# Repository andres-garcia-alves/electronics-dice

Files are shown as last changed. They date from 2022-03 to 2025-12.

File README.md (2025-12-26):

# Electronic-Dice

Arduino &amp; PIC16F84A source code & building details for an electronic dice (with animations). 

Available animations:
- #01: corner leds followed by the central one
- #02: perimeter leds followed by the central one
- #03: loop row-by-row from upper to bottom
- #04: bounce row-by-row from upper to bottom
- #05: go one-by-one over leds perimeter
- #06: a dot going in horizontal lines
- #07: a dot going in vertical lines
- #08: a dot going in zig-zag
- #09: loop of horizontal and vertical lines
- #10: a dot going in vertical lines followed by horizontal ones
- #11: random dots
- #12: random dots fill
- #13: random dot fill & random dot empty

&nbsp;

This project use the following electronic components:
-  1 x Arduino UNO / Nano v3
-  1 x push-button
-  1 x switch-button
-  7 x red LEDs
-  7 x 330 ohm resistors
-  1 x ON/OFF button
-  1 x blue LED
-  1 x 10k ohm resistor
-  1 x experimental board (single face) 6x8cm
-  1 x experimental board (double face) 6x8cm
-  1 x 9v battery
-  1 x small plastic box
- 10 x short female wires
- 20 x male 90 degrees pins

The circuit:
- Dice button attached to pin 2
- Switch button attached to pin 3 (enable/disable animations)
- Red LEDs attached to pins 4-10 (see code comments for details)

Pinout:

      *(A)        *(B)

      *(C)  *(D)  *(E)

      *(F)        *(G)

  - D02 -> input with button interrupt
  - D03 -> input with switch
  - D04 -> output to bottom-right led (G)
  - D05 -> output to middle-right led (E)
  - D06 -> output to upper-right led (B)
  - D07 -> output to middle-center led (D)
  - D08 -> output to bottom-left led (F)
  - D09 -> output to middle-left led (C)
  - D10 -> output to upper-left led (A)

&nbsp;

### Screenshots

| Schematics | PCB Layout |
|---|---|
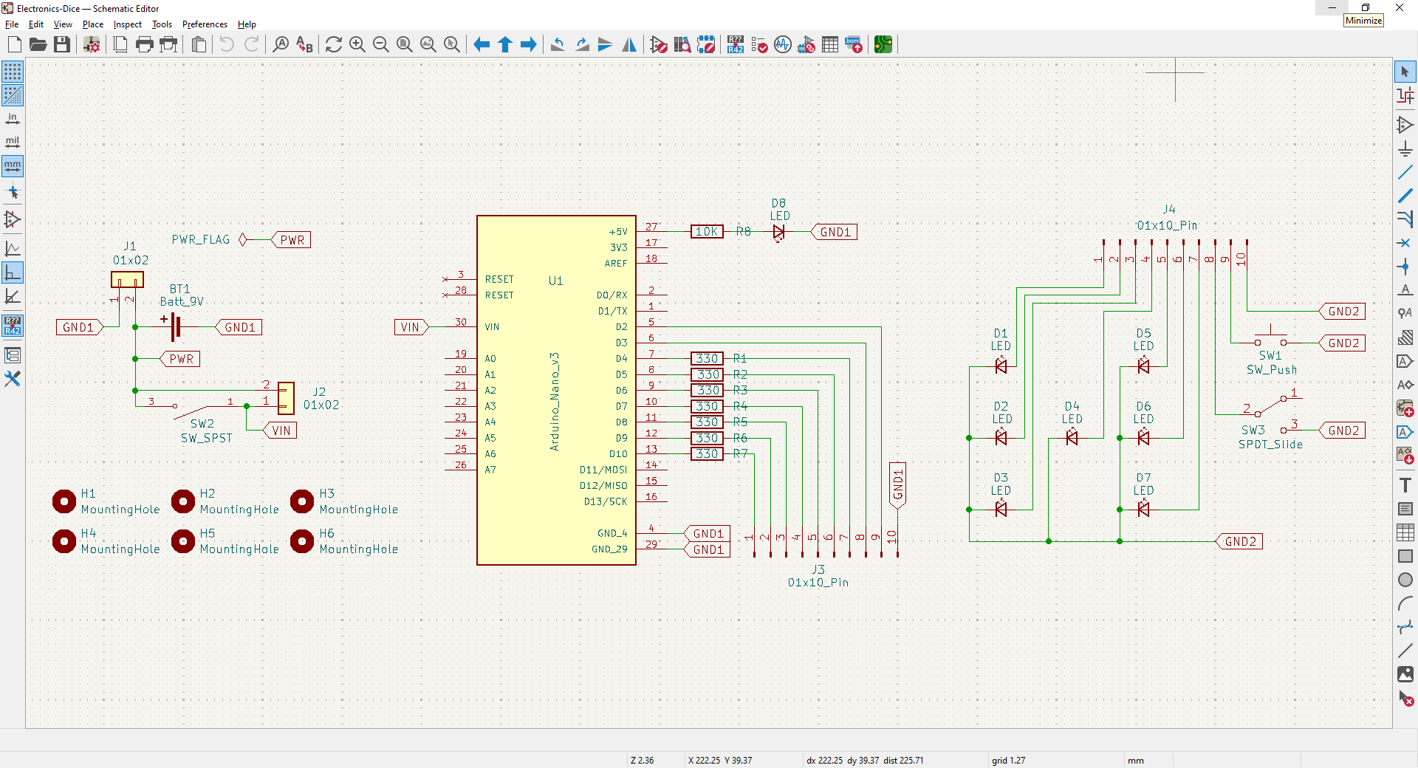
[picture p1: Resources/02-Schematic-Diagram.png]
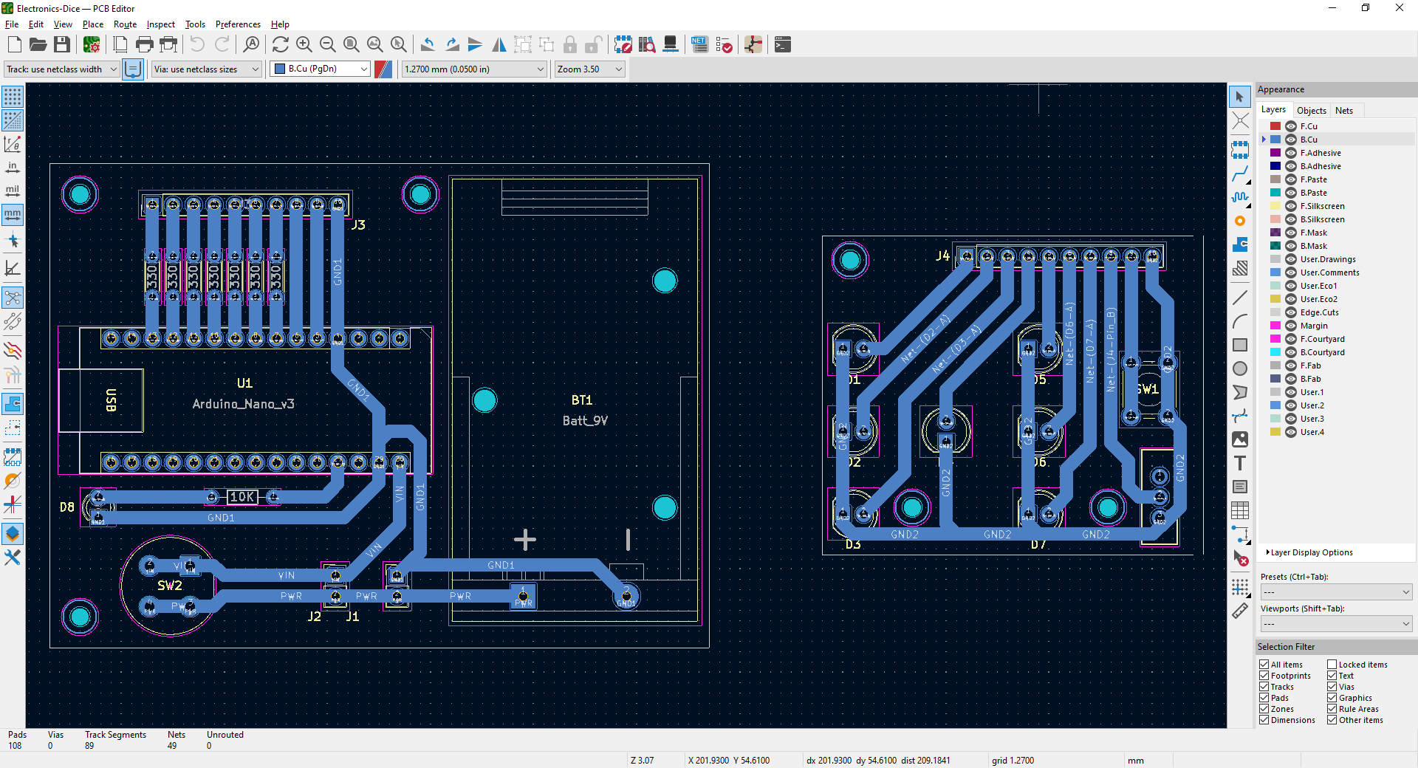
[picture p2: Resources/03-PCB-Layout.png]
|   |  |

| PCB 3D Render | PCB 3D Render |
|---|---|
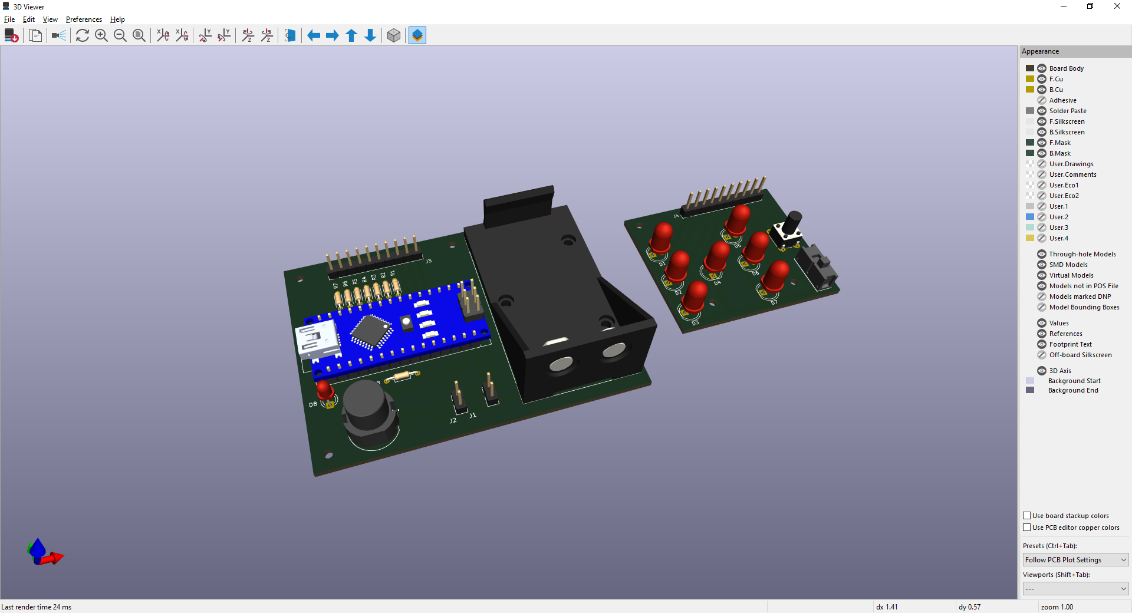
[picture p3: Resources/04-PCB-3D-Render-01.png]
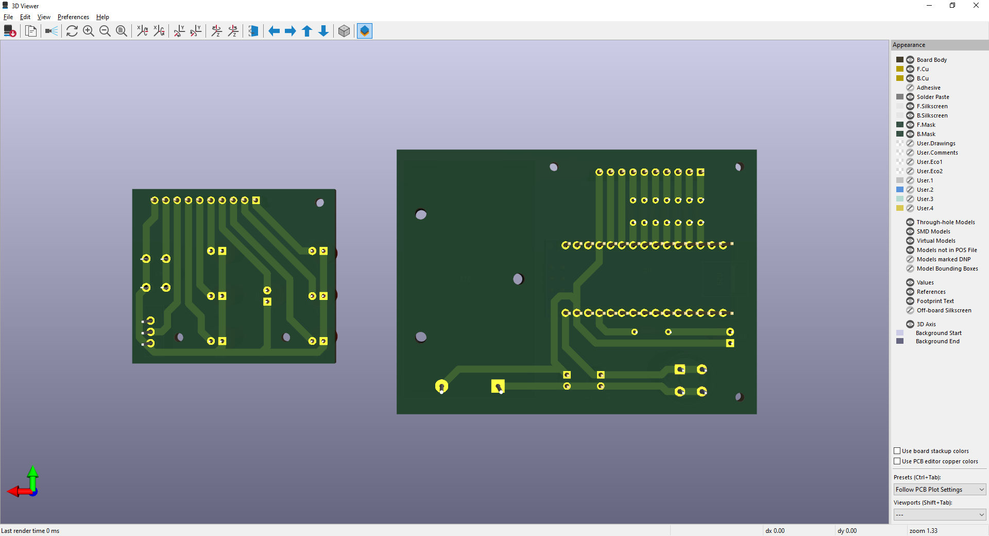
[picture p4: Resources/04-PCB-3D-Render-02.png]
|  |  |

| Prototype |  Prototype |
|---|---|
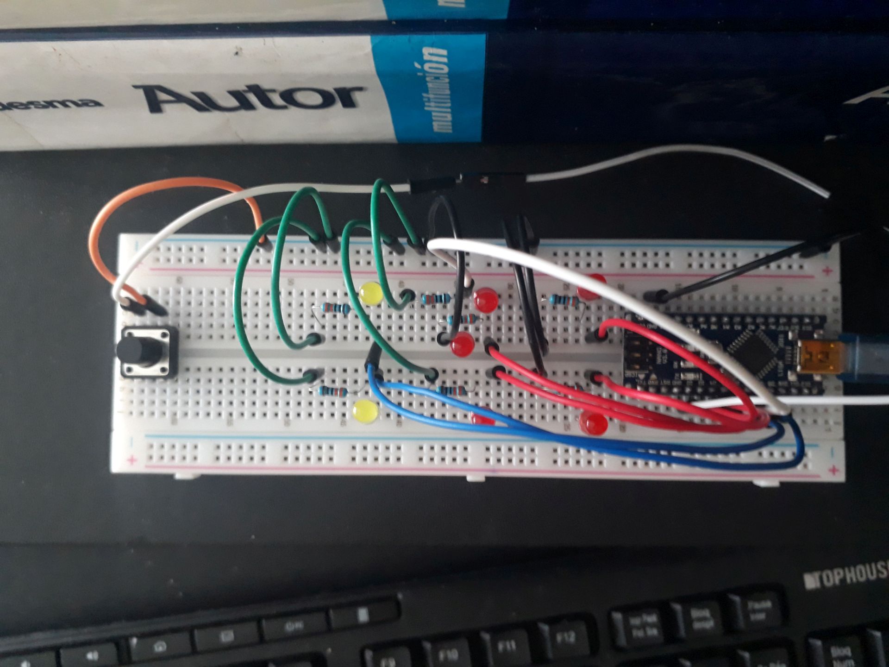
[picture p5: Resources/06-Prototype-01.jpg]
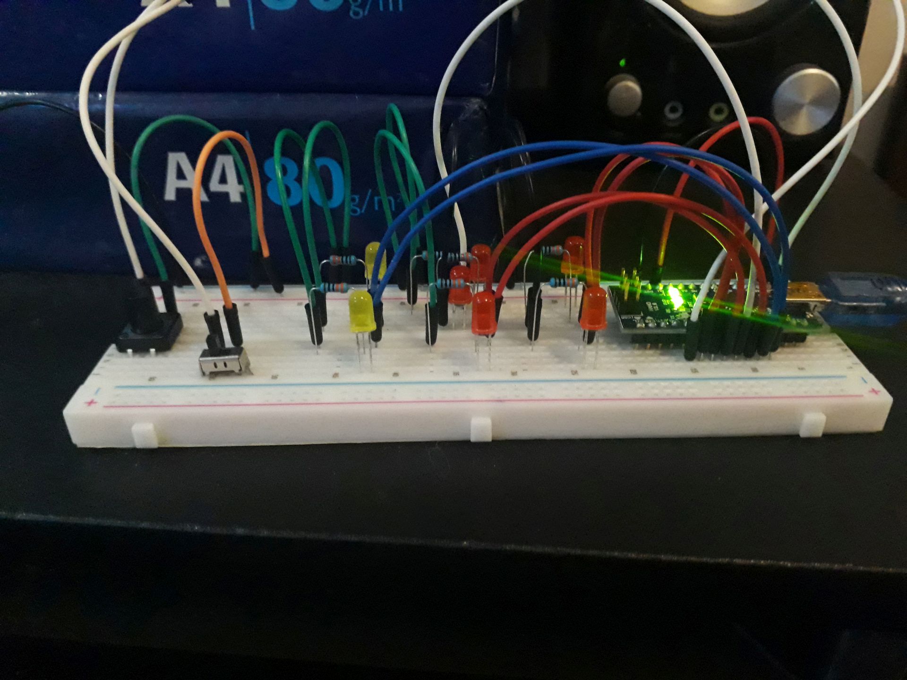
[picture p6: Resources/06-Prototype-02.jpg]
|  |  |

| Building |  Building |
|---|---|
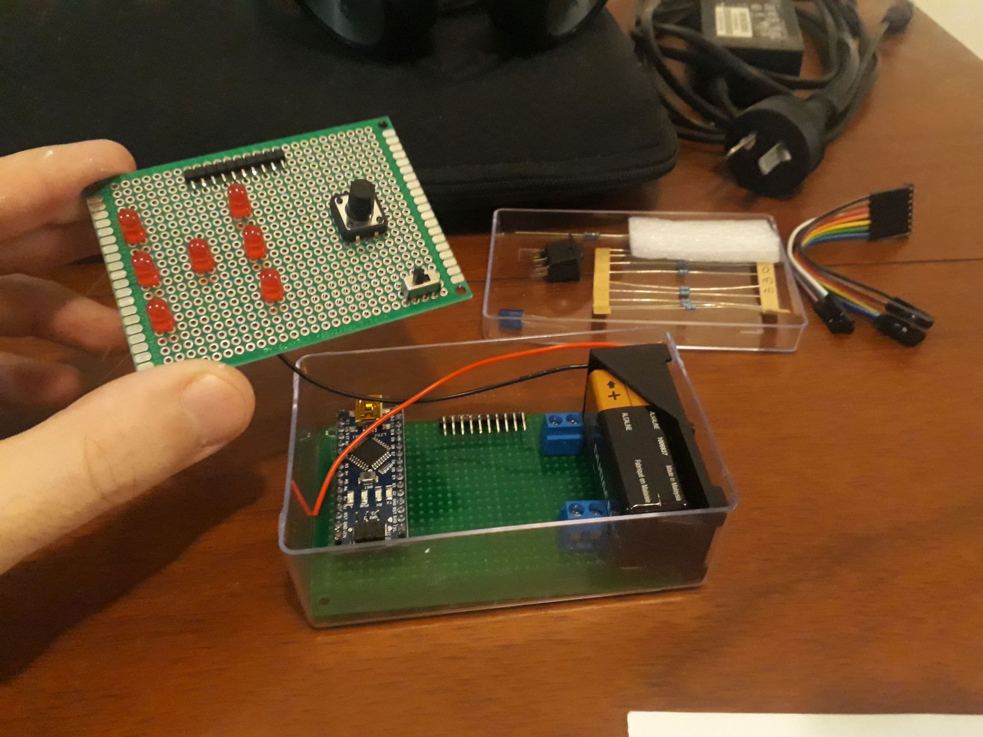
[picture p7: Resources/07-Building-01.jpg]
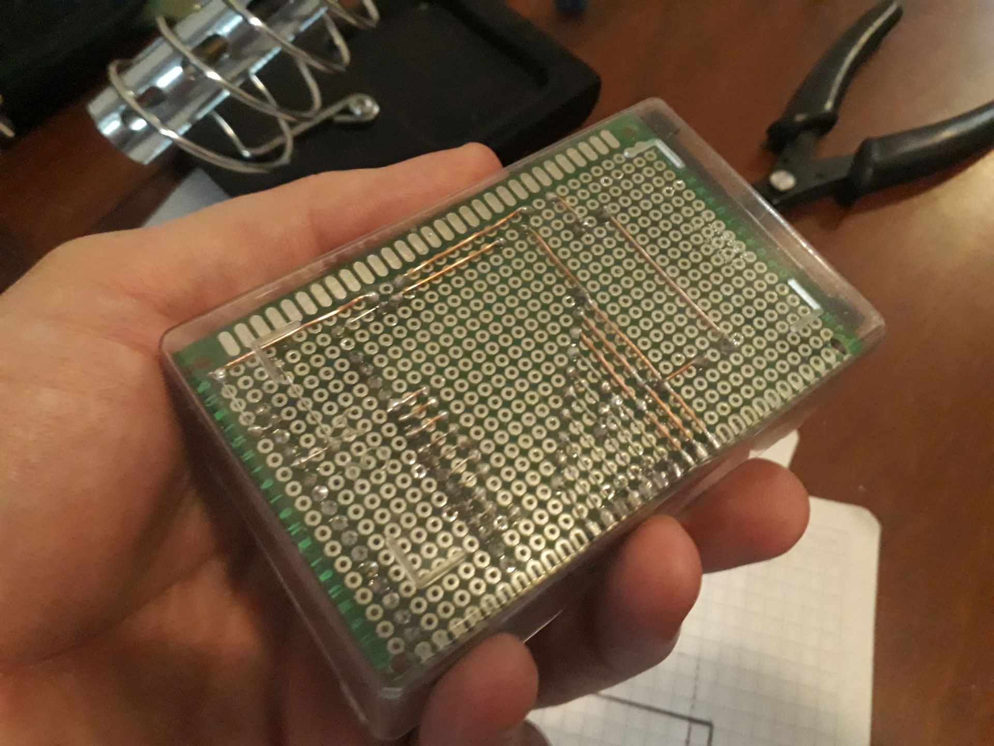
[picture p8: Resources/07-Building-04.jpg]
|  |  |

| Building |  Building |
|---|---|
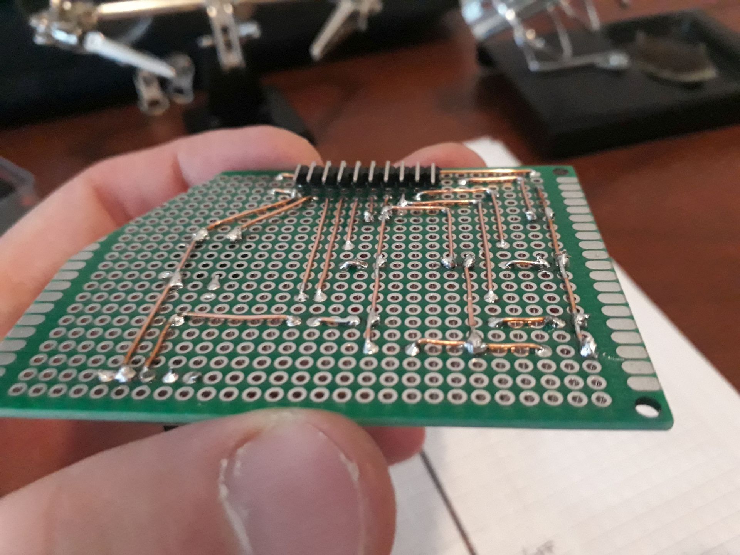
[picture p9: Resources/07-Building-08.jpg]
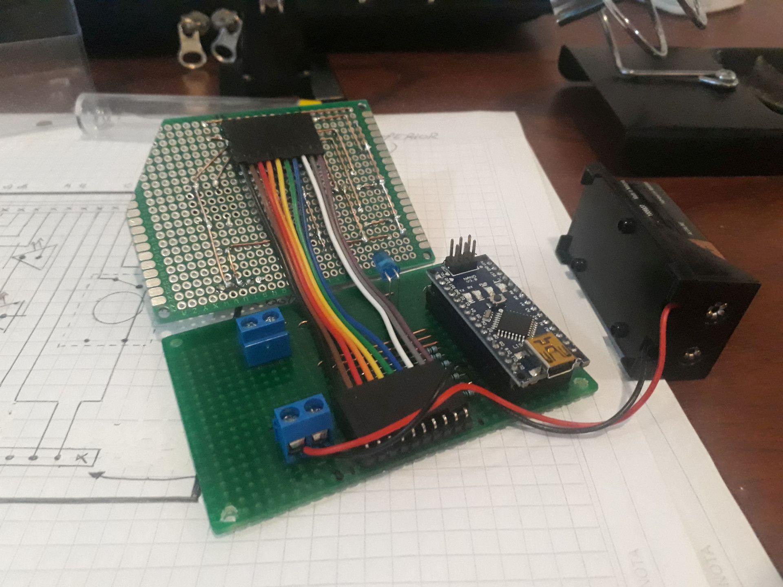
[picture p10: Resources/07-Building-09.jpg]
|  |  |

| Project Final | Project Final (YouTube video) |
|---|---|
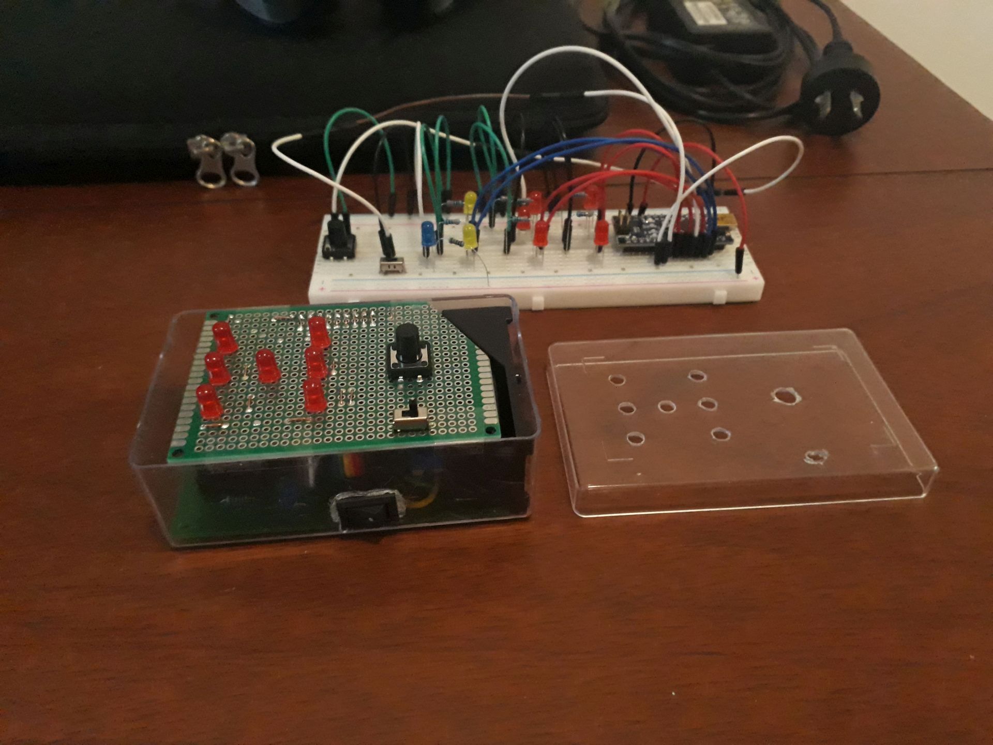
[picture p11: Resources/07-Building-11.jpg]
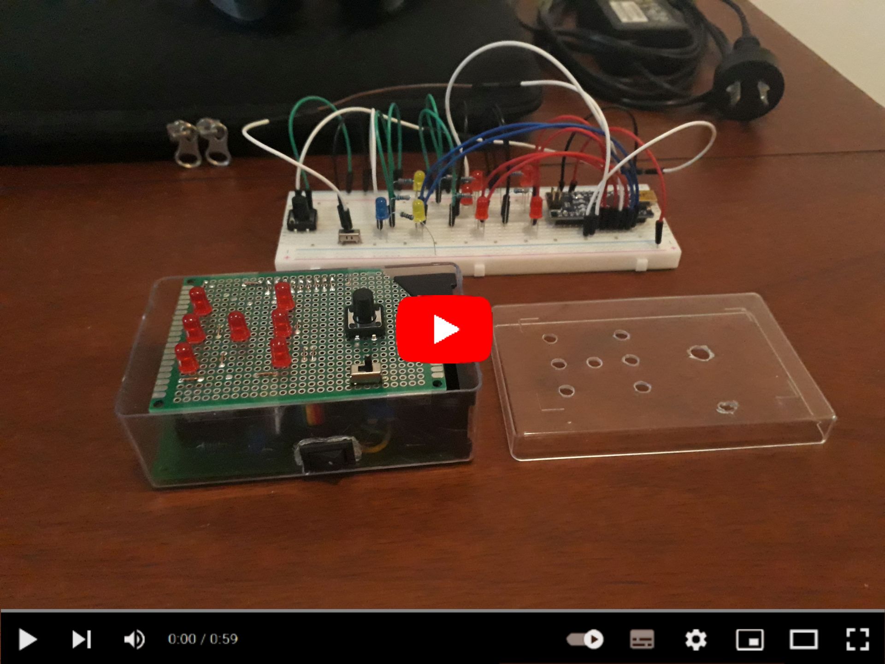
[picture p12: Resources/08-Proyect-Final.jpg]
(https://youtu.be/CFKjGjXlMMI)
|  |  |

See 'Rescources' sub-folder for more pictures & videos of the project.

&nbsp;

### Version History

v1.0 (2022.02.23) - Initial release.  
v1.1 (2022.02.24) - Adding ON/OFF animations switch. Fixed bug with random secuences (randomSeed).  
v1.2 (2022.02.27) - Re-arrange LEDs pin-out to simplify PCB.  
v1.3 (2022.03.09) - Animations improved with ROM tables: line count 622->342 (compiled size reduced by 20%).  
v1.4 (2022.03.10) - Dice number improved with masked bits: line count 342 -> 296.  
v1.5 (2025.12.26) - Adding KiCAD 9 schematics and PCB diagrams.

&nbsp;

This source code is licensed under GPL v3.0  
Please send me your feedback about this project: andres.garcia.alves@gmail.com

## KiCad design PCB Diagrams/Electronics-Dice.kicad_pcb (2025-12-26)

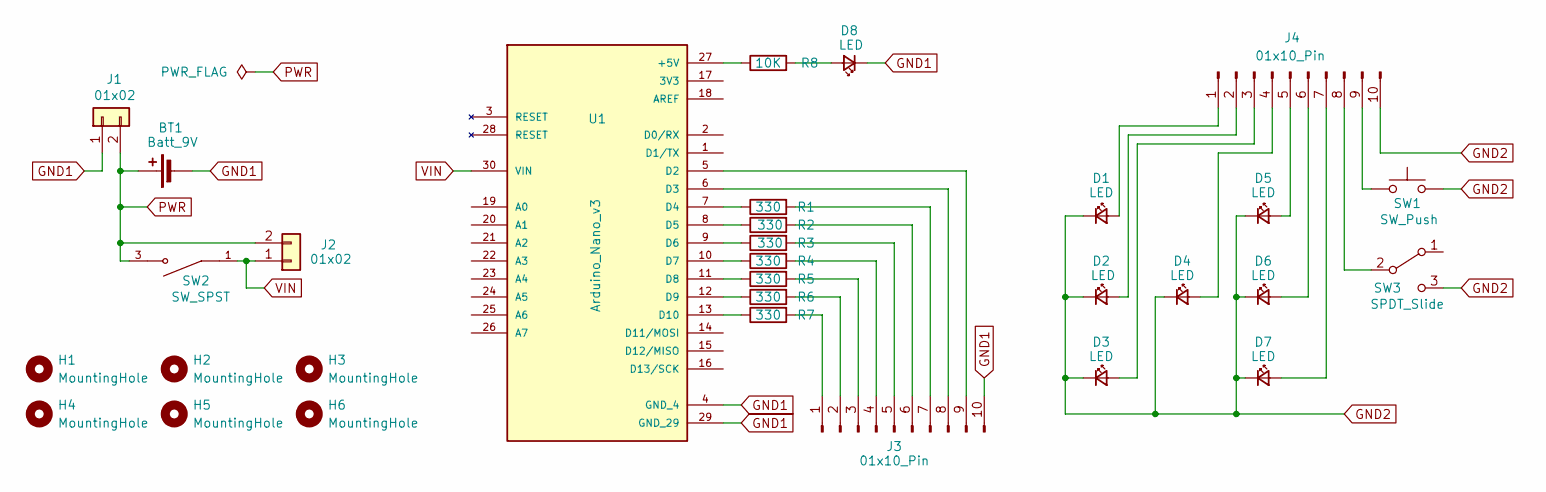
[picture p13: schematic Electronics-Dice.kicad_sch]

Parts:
BT1: Batt_9V; BatteryHolder_Eagle_12BH611-GR
D1, D2, D3, D4, D5, D6, D7: LED; LED_D5.0mm
D8: LED; LED_D3.0mm
H1, H2, H3, H4, H5, H6: MountingHole; MountingHole_2mm
J1, J2: 01x02; PinHeader_1x02_P2.54mm_Vertical
J3, J4: 01x10_Pin; PinHeader_1x10_P2.54mm_Vertical
R1, R2, R3, R4, R5, R6, R7: 330; R_Axial_DIN0204_L3.6mm_D1.6mm_P5.08mm_Horizontal
R8: 10K; R_Axial_DIN0204_L3.6mm_D1.6mm_P7.62mm_Horizontal
SW1: SW_Push; SW_PUSH_6mm_H9.5mm
SW2: SW_SPST; Push_Button_Switch_THT_C&K_D6R90LGS
SW3: SPDT_Slide; Slide_SPDT_PTH_11.6x4.0mm
U1: Arduino_Nano_v3

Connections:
GND1: BT1.2 (-), D8.1 (K), J1.1, J3.10, U1.4 (GND_4), U1.29 (GND_29)
GND2: D1.1 (K), D2.1 (K), D3.1 (K), D4.1 (K), D5.1 (K), D6.1 (K), D7.1 (K), J4.10, SW1.2, SW3.3 (C)
unnamed: D1.2 (A), J4.1
unnamed: D2.2 (A), J4.2
unnamed: D3.2 (A), J4.3
unnamed: D4.2 (A), J4.4
unnamed: D5.2 (A), J4.5
unnamed: D6.2 (A), J4.6
unnamed: D7.2 (A), J4.7
unnamed: D8.2 (A), R8.2
unnamed: J3.1, R7.2
unnamed: J3.2, R6.2
unnamed: J3.3, R5.2
unnamed: J3.4, R4.2
unnamed: J3.5, R3.2
unnamed: J3.6, R2.2
unnamed: J3.7, R1.2
unnamed: J3.8, U1.6 (D3)
unnamed: J3.9, U1.5 (D2)
unnamed: J4.8, SW3.2 (B)
unnamed: J4.9, SW1.1
unnamed: R8.1, U1.27 (+5V)
unnamed: R1.1, U1.7 (D4)
unnamed: R2.1, U1.8 (D5)
unnamed: R3.1, U1.9 (D6)
unnamed: R4.1, U1.10 (D7)
unnamed: R5.1, U1.11 (D8)
unnamed: R6.1, U1.12 (D9)
unnamed: R7.1, U1.13 (D10)
PWR: BT1.1 (+), J1.2, J2.2, SW2.3, SW2.4
VIN: J2.1, SW2.1, SW2.2, U1.30 (VIN)

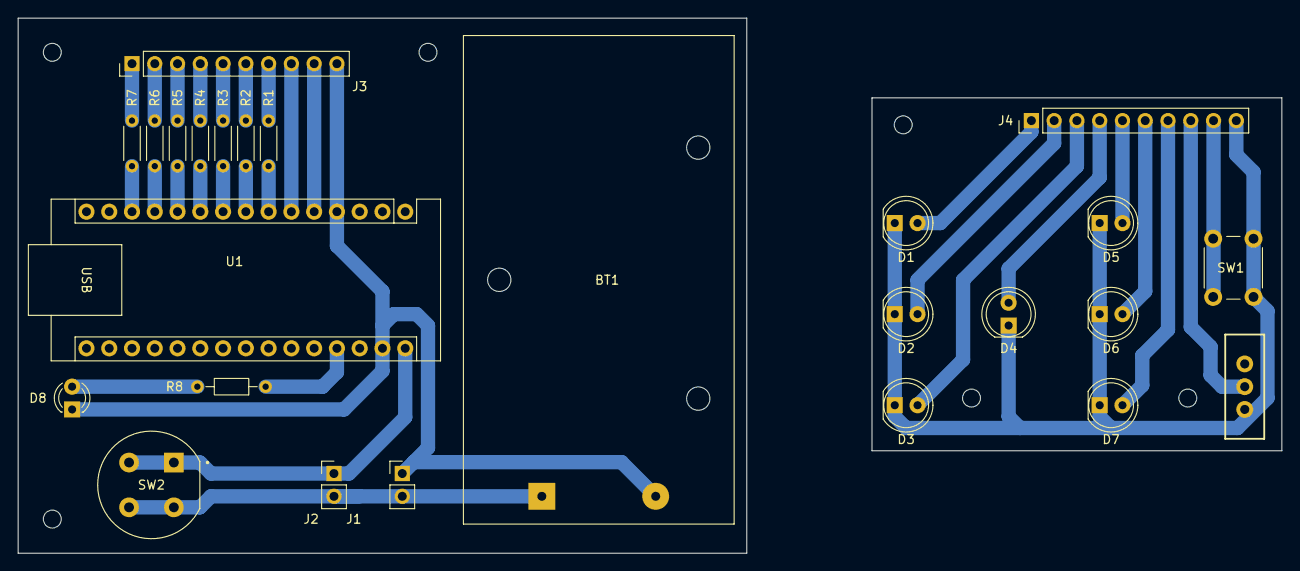
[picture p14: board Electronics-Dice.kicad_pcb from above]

Board: 2 copper layers, 141.0 x 59.7 mm, 31 parts (0 on the bottom side), 31 nets.

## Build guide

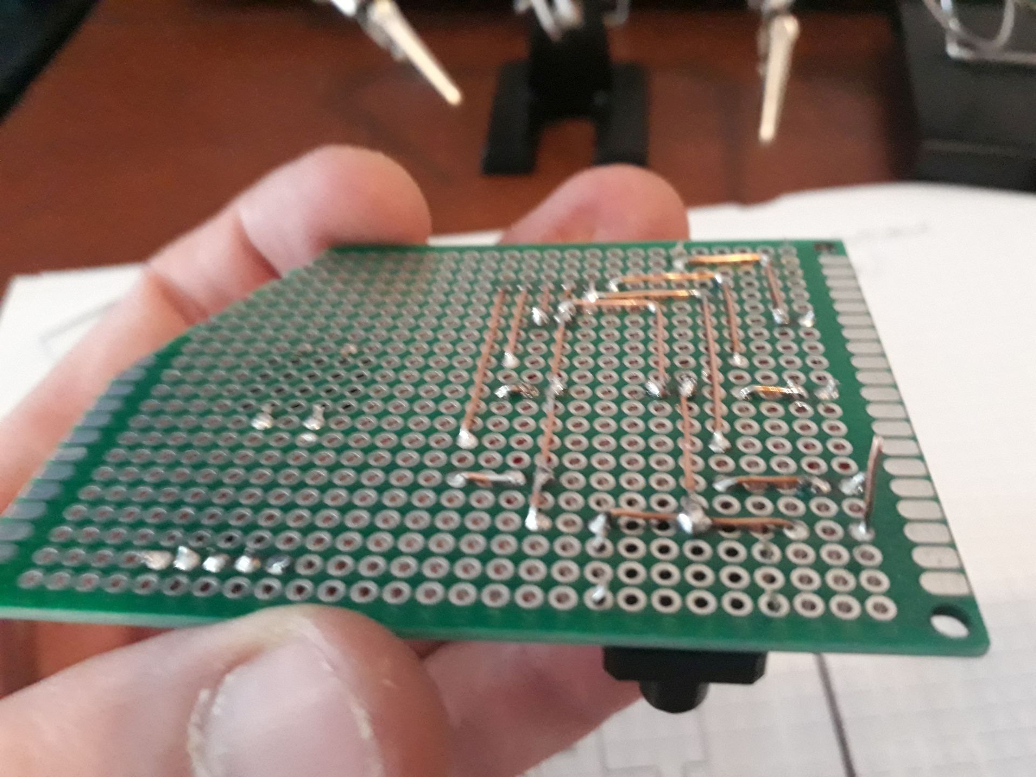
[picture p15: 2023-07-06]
Resources/07-Building-07.jpg

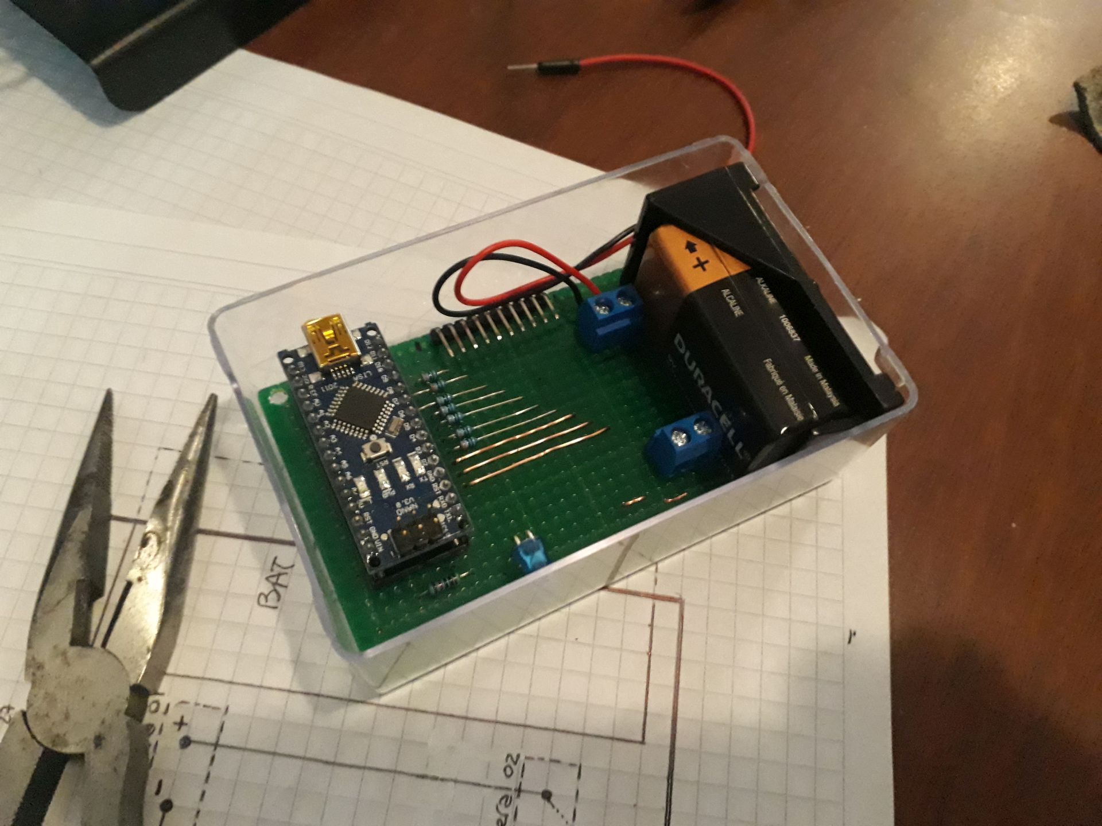
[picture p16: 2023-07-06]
Resources/07-Building-03.jpg

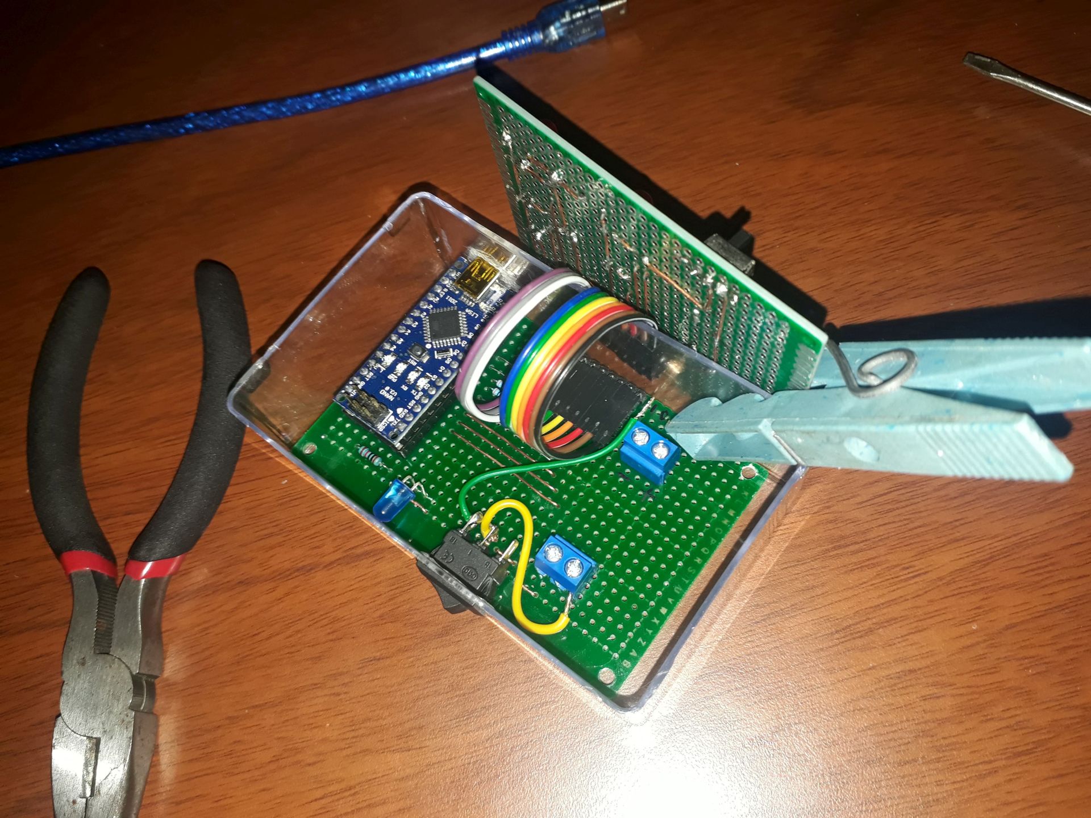
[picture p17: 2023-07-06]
Resources/07-Building-10.jpg

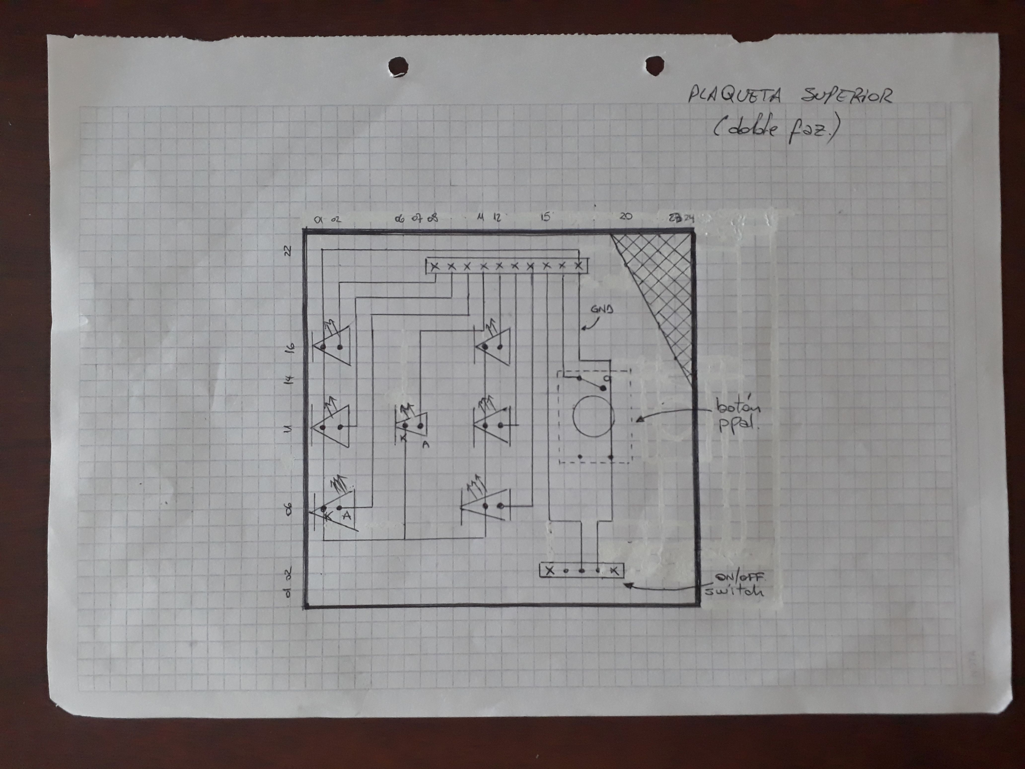
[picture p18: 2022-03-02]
Resources/01-Wiring-Diagram-01.jpg

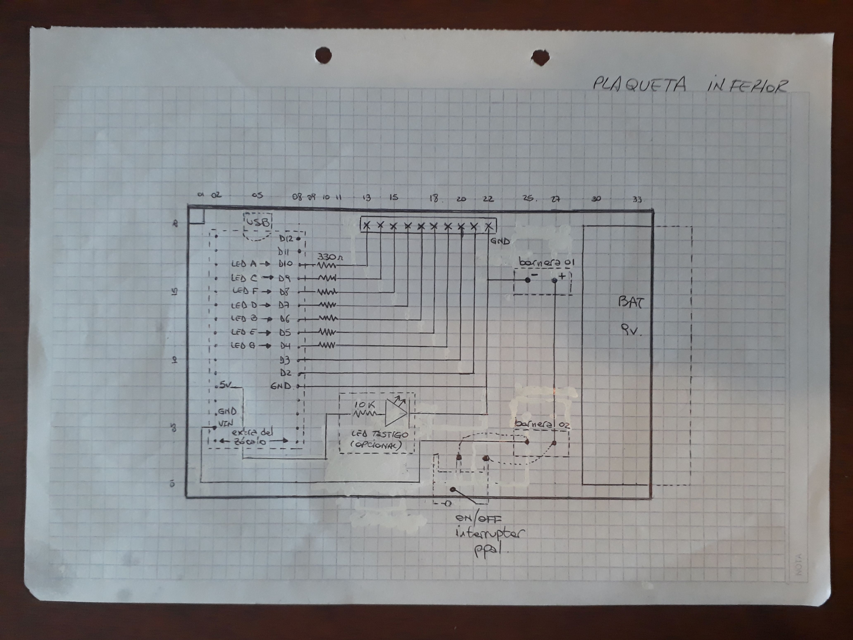
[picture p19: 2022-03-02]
Resources/01-Wiring-Diagram-02.jpg

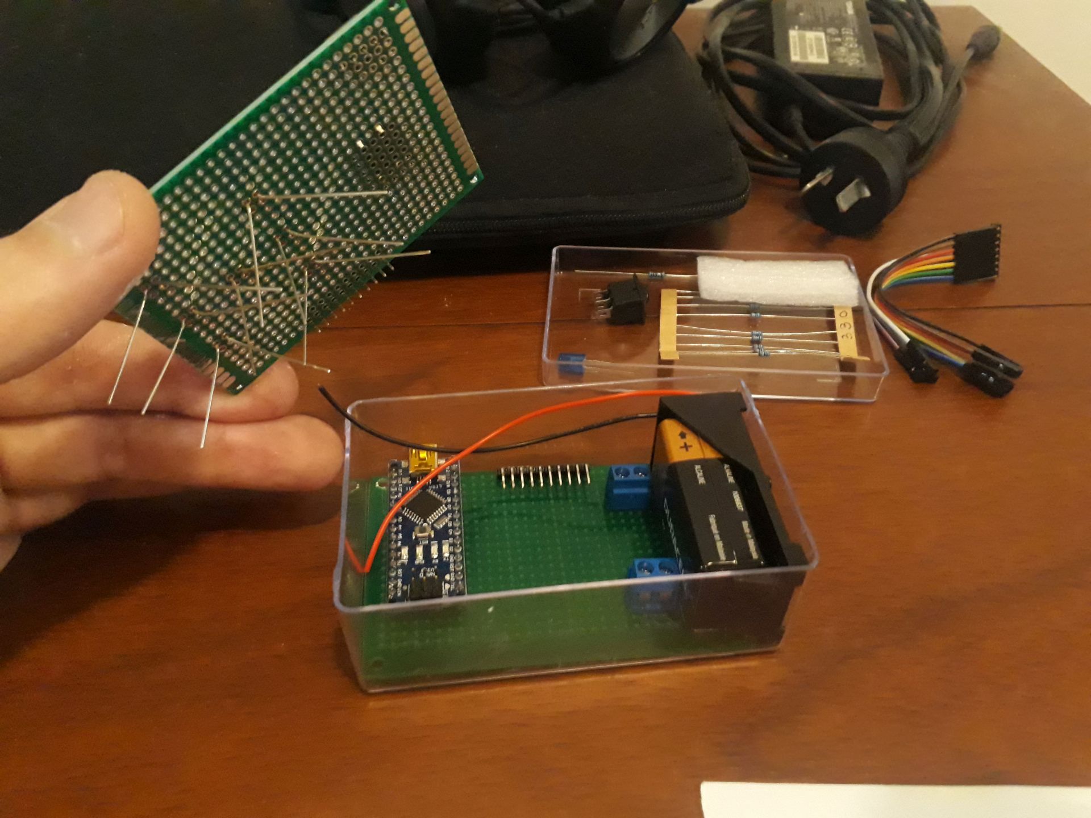
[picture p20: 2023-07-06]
Resources/07-Building-02.jpg

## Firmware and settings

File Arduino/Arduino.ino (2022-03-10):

/*
  Electronic Dice v1.3

  Created by: Andres Garcia Alves <andres.garcia.alves@gmail.com>
  Microcontroller: Arduino Nano (ATMega328 @16Mhz)
  
  Version 1.0, 2022.02.23 - Initial release.
  Version 1.1, 2022.02.24 - Adding ON/OFF animations switch.
                            Fixed bug with random secuences (randomSeed).
  Version 1.2, 2022.02.27 - Re-arrange LEDs pin-out to simplify PCB.
  Version 1.3, 2022.03.09 - Animations improvement using ROM tables: lines count 622->342, compiled total size 6031->4867 bytes (20% reduction).
  Version 1.4, 2022.03.10 - Dice number improvement using masked bits: lines count 342->296, compiled total size 4867->4777 bytes (2% reduction).

  This source code is licensed under GPL v3.0  

  Pinout:
  
      *(A)        *(B)

      *(C)  *(D)  *(E)

      *(F)        *(G)

  D02 -> input with button interrupt
  D03 -> input with switch
  D04 -> output to bottom-right led (G)
  D05 -> output to middle-right led (E)
  D06 -> output to upper-right led (B)
  D07 -> output to middle-center led (D)
  D08 -> output to bottom-left led (F)
  D09 -> output to middle-left led (C)
  D10 -> output to upper-left led (A)
*/

#include <LowPower.h>

// const & variables
const int PIN_BTN = 2;
const int PIN_SWITCH = 3;

const int PIN_LED_A = 10;
const int PIN_LED_B = 6;
const int PIN_LED_C = 9;
const int PIN_LED_D = 7;
const int PIN_LED_E = 5;
const int PIN_LED_F = 8;
const int PIN_LED_G = 4;

const int DEBOUNCE_DELAY = 50;
const int DICE_DELAY = 5000;

const int ANIM_COUNT = 13;
const int ANIM_SPEED_IDX = 0;
const int ANIM_LOOPS_IDX = 1;
const int ANIM_LENGHT_IDX = 2;

const int ANIM_DELAY = 200;
const int ANIM_HALF_DELAY = 100;
const int ANIM_DOUBLE_DELAY = 400;
const int ANIM_ENDING_DELAY = 1000;

// interrupt handlers
void btnInterruptHandler() { }
 

// initial setup
void setup() {

  // CLKPR = 0x80; // (1000 0000) enable change in clock frequency
  // CLKPR = 0x01; // (0000 0001) use clock division factor 2 to reduce the frequency from 16 MHz to 8 MHz

  Serial.begin(9600);

  pinMode(PIN_BTN, INPUT_PULLUP);
  pinMode(PIN_SWITCH, INPUT_PULLUP);
  pinMode(PIN_LED_A, OUTPUT);
  pinMode(PIN_LED_B, OUTPUT);
  pinMode(PIN_LED_C, OUTPUT);
  pinMode(PIN_LED_D, OUTPUT);
  pinMode(PIN_LED_E, OUTPUT);
  pinMode(PIN_LED_F, OUTPUT);
  pinMode(PIN_LED_G, OUTPUT);

  // get some noise value from A0
  randomSeed(analogRead(A0));

  // enable external interrupts on pins 2 & 3
  attachInterrupt(digitalPinToInterrupt(PIN_BTN), btnInterruptHandler, FALLING);
}


// main loop
void loop() {

  // enter in power-down state
  LowPower.powerDown(SLEEP_FOREVER, ADC_OFF, BOD_ON);

  // main button logic
  checkButtonPressed();
}


void checkButtonPressed() {

  // de-bounce delay
  delay(DEBOUNCE_DELAY);
  bool btnStatus = digitalRead(PIN_BTN);
  if (btnStatus != LOW) { return; }

  // throw the dice
  byte diceNumber = (byte)random(1, 7); // range 1-6
  byte animNumber = (byte)random(1, ANIM_COUNT+1); // range 1-ANIM_COUNT

  // animation
  bool switchAnim = digitalRead(PIN_SWITCH);
  if (switchAnim == true) {
    displayAnimation(animNumber);
    delay(ANIM_ENDING_DELAY);
  }

  // display dice number & fade-out
  displayDiceNumber(diceNumber);
  delay(DICE_DELAY);
  animateDiceNumber(diceNumber);
}


void displayDiceNumber(byte diceNumber) {

  clearDice();

  // dice numbers: 0 (invalid), 1, 2, 3, 4, 5, 6
  byte numbersData[7] = { 0b00000000, 0b00001000, 0b01000001, 0b01001001, 0b01100011, 0b01101011, 0b01110111 };

  // set individuals leds ON/OFF by mask (format: 0XXXXXXX)
  displayLedsByMaskedBits(numbersData[diceNumber], HIGH);
}

void animateDiceNumber(byte diceNumber) {
  
  for (int i = 0; i < 6; i++) {
    displayDiceNumber(diceNumber);
    delay(ANIM_DOUBLE_DELAY);
    clearDice();
    delay(ANIM_DELAY);
  }
}


// display an animation by number
void displayAnimation(byte animNumber) {
  
  switch (animNumber) {
    case 1 ... 10: displayStaticAnimation(animNumber); break;
    case 11: displayDynamicAnimation1(); break;
    case 12: displayDynamicAnimation2(); break;
    case 13: displayDynamicAnimation3(); break;
  }
}

// anims #01-10: static animations
void displayStaticAnimation(byte animNumber) {

  // row format: [speed], [loops], [length], [bitmask step #1], [bitmask step #2], [bitmask step #n], [0]
  byte animationsData[10][16] = {
    { 1,  8,  2,  99,   8,   0,   0,   0,   0,   0,   0,   0,   0,   0,   0,   0 }, // #01: corner leds followed by the central one (16 ticks)
    { 1,  8,  2, 119,   8,   0,   0,   0,   0,   0,   0,   0,   0,   0,   0,   0 }, // #02: perimeter leds followed by the central one (16 ticks)
    { 1,  6,  3,   3,  28,  96,   0,   0,   0,   0,   0,   0,   0,   0,   0,   0 }, // #03: loop row-by-row from upper to bottom (18 ticks)
    { 1,  4,  4,   3,  28,  96,  28,   0,   0,   0,   0,   0,   0,   0,   0,   0 }, // #04: bounce row-by-row from upper to bottom (16 ticks)
    { 0,  6,  6,   1,   2,  16,  64,  32,   4,   0,   0,   0,   0,   0,   0,   0 }, // #05: go one-by-one over leds perimeter (18 ticks)
    { 0,  5,  7,   1,   2,   4,   8,  16,  32,  64,   0,   0,   0,   0,   0,   0 }, // #06: a dot going in horizontal lines (17.5 ticks)
    { 0,  6,  6,   1,   4,  32,   2,  16,  64,   0,   0,   0,   0,   0,   0,   0 }, // #07: a dot going in vertical lines (18 ticks)
    { 0,  6,  6,   1,  16,  32,  64,   4,   2,   0,   0,   0,   0,   0,   0,   0 }, // #08: a dot going in zig-zag (18 ticks)
    { 1,  2,  8,   3,  82,  28,  37,  96,  82,  28,  37,   0,   0,   0,   0,   0 }, // #09: loop of horizontal and vertical lines (16 ticks)
    { 0,  3, 13,   1,   4,  32,   2,  16,  64,   1,   2,   4,   8,  16,  32,  64 }  // #10: a dot going in vertical lines followed by horizontal ones (19.5 ticks)
  };
  
  byte animStepData;
  byte animSpeed = animationsData[animNumber -1][ANIM_SPEED_IDX]; // idx 00
  byte animLoops = animationsData[animNumber -1][ANIM_LOOPS_IDX]; // idx 01
  byte animLenght = animationsData[animNumber -1][ANIM_LENGHT_IDX]; // idx 02

  for (int i = 0; i < animLoops; i++) {
    for (int j = 3; j < animLenght +3; j++) {

      // set individuals leds ON/OFF by mask
      animStepData = animationsData[animNumber -1][j];
      displayLedsByMaskedBits(animStepData, HIGH);
  
      delay(animSpeed == 0 ? ANIM_HALF_DELAY : ANIM_DELAY);
      clearDice();    
    }
  }
}

// anim #11: random dots (18 ticks)
void displayDynamicAnimation1() {

  for (int i = 0; i < 36; i++) {
    
    byte ledNumber = (byte)random(1, 8); // range 1-7
    displayLedByNumber(ledNumber, HIGH);
    
    delay(ANIM_HALF_DELAY);
    clearDice();
  }
}

// anim #12: random dots fill (9 x 2 -> 18 ticks)
void displayDynamicAnimation2() {
  byte idx;

  for (int i = 0; i < 2; i++) {
    bool empty[7] = {true, true, true, true, true, true, true};

    for (int j = 0; j < 7; j++) {
      do {
        idx = (byte)random(0, 7); // range 0-6
      } while (empty[idx] == false);
      empty[idx] = false;

      displayLedByNumber(idx+1, HIGH);
      delay(ANIM_DELAY);
    }

    delay(ANIM_DOUBLE_DELAY);
    clearDice();
  }
}

// anim #13: random dot fill & random dot empty (9 + 9 -> 18 ticks)
void displayDynamicAnimation3() {
  byte idx;
  bool empty[7] = {true, true, true, true, true, true, true};

  // random fill
  for (int i = 0; i < 7; i++) {
    do {
      idx = (byte)random(0, 7); // range 0-6
    } while (empty[idx] == false);
    empty[idx] = false;

    displayLedByNumber(idx+1, HIGH);
    delay(ANIM_DELAY);
  }

  delay(ANIM_DOUBLE_DELAY);

  // random empty
  for (int j = 0; j < 7; j++) {
    do {
      idx = (byte)random(0, 7); // range 0-6
    } while (empty[idx] == true);
    empty[idx] = true;

    displayLedByNumber(idx+1, LOW);
    delay(ANIM_DELAY);
  }

  delay(ANIM_DOUBLE_DELAY);
  clearDice();
}


// set all leds OFF
void clearDice() {

  // set individuals leds ON/OFF by mask (format: 0XXXXXXX)
  displayLedsByMaskedBits(0b11111111, LOW);
}

// set an individual led ON/OFF by number
void displayLedByNumber(byte ledNumber, boolean ledStatus) {
  
  switch (ledNumber) {
    case 1: digitalWrite(PIN_LED_A, ledStatus); break;
    case 2: digitalWrite(PIN_LED_B, ledStatus); break;
    case 3: digitalWrite(PIN_LED_C, ledStatus); break;
    case 4: digitalWrite(PIN_LED_D, ledStatus); break;
    case 5: digitalWrite(PIN_LED_E, ledStatus); break;
    case 6: digitalWrite(PIN_LED_F, ledStatus); break;
    case 7: digitalWrite(PIN_LED_G, ledStatus); break;
  }
}

// set individuals leds ON/OFF by mask (format: 0XXXXXXX)
void displayLedsByMaskedBits(byte maskedBits, boolean ledStatus) {
  
    if (maskedBits & 1) { digitalWrite(PIN_LED_A, ledStatus); }
    if (maskedBits & 2) { digitalWrite(PIN_LED_B, ledStatus); }
    if (maskedBits & 4) { digitalWrite(PIN_LED_C, ledStatus); }
    if (maskedBits & 8) { digitalWrite(PIN_LED_D, ledStatus); }
    if (maskedBits & 16) { digitalWrite(PIN_LED_E, ledStatus); }
    if (maskedBits & 32) { digitalWrite(PIN_LED_F, ledStatus); }
    if (maskedBits & 64) { digitalWrite(PIN_LED_G, ledStatus); }
}
